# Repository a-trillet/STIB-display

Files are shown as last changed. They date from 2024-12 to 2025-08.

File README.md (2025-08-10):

# Brussels transport lines Display
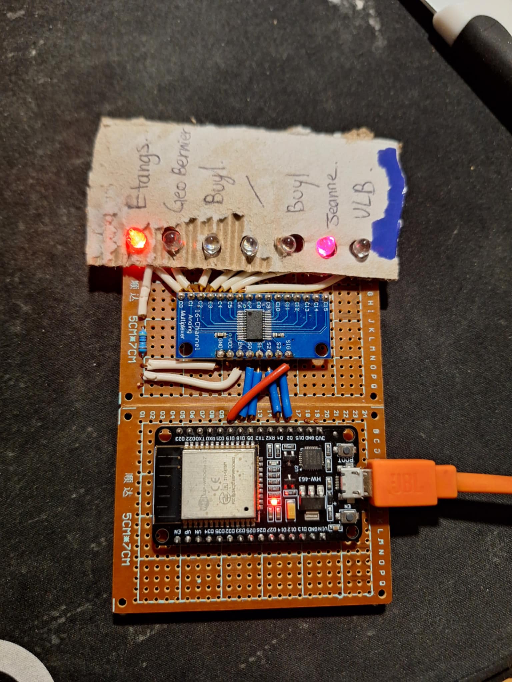
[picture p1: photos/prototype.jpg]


## What you need
- ESP32 devkit (we used esp32 WROOM devkit1)
- 16 channel MUX (for maximum 16 LEDs)
- basic electronic componenents (leds, resistor, test board or PCB...)  

(Not yet ready !)
For a complete list of electronic components and the references we used, refer to [hardware section](./hardware/).   
In the same section, the PCB kicad files can be downloaded and you can order them through any PCB manufacturer. 

## Getting started with the STIB API
- Create an account on https://data.stib-mivb.brussels/pages/home/
- Generate API key on https://data.stib-mivb.brussels/account/api-keys/
- Test the api with [request.py](./pc-test/request.py)
    - Change the ****  in the request header with the generated API key
    - Running `python request.py` will show buses location on line 71, you will want to adapt stop IDs to the line you are interested in. You can get all stop IDs for all lines using the WEB API for stops information:  [stops-by-line-production](https://data.stib-mivb.brussels/explore/dataset/stops-by-line-production/api/)

## Getting started on ESP 32
The following steps and requirements are provided for Windows.
- Download the latest micropython firmware for esp32 here : [micropython firmware](https://micropython.org/download/ESP32_GENERIC/)
- Download useful python tools: 
    - `pip install esptool`
    - `pip install adafruit-ampy`
- Erase flash of ESP: `python -m esptool --chip esp32 erase_flash`
- Flash ESP with micropython firmware: `python -m esptool --chip esp32 --port COMX write_flash -z 0x1000 ESP32_GENERIC-20241129-v1.24.1.bin`
- Adpat **** in main.py with your API key and Wifi credentials
- Send main.py to the ESP to be executed automatically: `<path\to\ampy.exe> --port COMX put <path\to\main.py>`
- Get buses position through serial communication (using Putty per example)
```
LED 3 activée
Bus à: 3559 - ULB vers Jeanne 3559
LED 5 activée
Bus à: 2397 - Buyl(delta) vers ULB 2397
LED 3 activée
Bus à: 3525 - Jeanne vers Buyl 3525
LED 4 activée
```

Like us, you might need to: 
- Download the CP210x driver for ESP USB to UART bridge: [download CP210x](https://www.silabs.com/developer-tools/usb-to-uart-bridge-vcp-drivers?tab=downloads)
- Change the baudrate for the discovered device in device manager to **115200**
- Don't forget to close putty before writing to it

Get more detailed steps: https://docs.micropython.org/en/latest/esp32/tutorial/intro.html  

## Make it ! 
Instructions, schematics and PCBs layout can be found under [hardware section](./hardware/). 

And in the code you will have to adapt the list of stops you want to see with the stop IDs available on STIB web API. Also you will have to change the channel number of each led that has to turn on in the dictionnary with bus stops. (currently only one MUX). 

## CC License 
All work in this project is openly licensed via [CC BY-NC 4.0](https://creativecommons.org/licenses/by-nc/4.0/).

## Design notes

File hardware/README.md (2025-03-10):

# PCB layout
Helpful ressources for kicad V8,: [Kicad 8 - Getting Started](https://docs.kicad.org/8.0/en/getting_started_in_kicad/getting_started_in_kicad.html)

PCB can easily be manufactured at any PCB manufacturer. I ordered mine at JCLPCB by uploading the gerber and drill files for each board.   
I had to regenerate those with one board only at a time (deleting the rest on the pcb layout). 
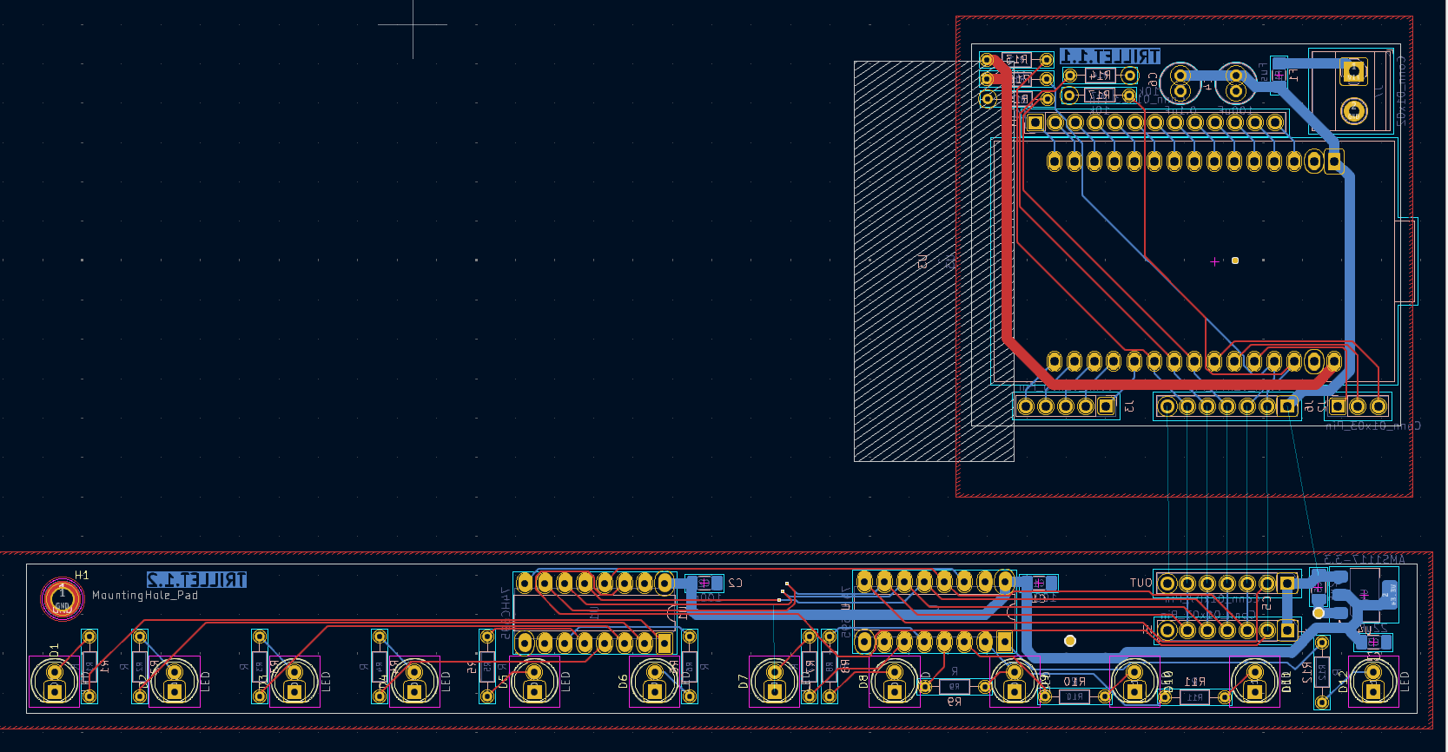
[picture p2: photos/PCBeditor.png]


The idea is to solder the LED boards in serie, one per line wanted in the final design: 
- J6 Pins of the ESP32 board (Trillet 1.1) go to IN pin of first LED board (Trillet 1.2)
- Pins OUT of the first LED board go to IN pin of the next LED board
## BOM 
### LED board
|Amount|Component|Ref number|
|-|-|-|
| 1 | 3.3v linear voltage regulator | [AMS1117-3.3V](https://www.alldatasheet.com/datasheet-pdf/pdf/205691/ADMOS/AMS1117-3.3.html) |
| 2 | 100nF SMD Capacitor | 100nF 1206 SMD:C |
| 2 | 22uF SMD Capacitor | 22uF 1206 SMD:C |
| 2 | 8bit shift register | [SN74HC595N (THT) ](https://www.alldatasheet.fr/datasheet-pdf/download/27939/TI/SN74HC595N.html) |
| 12 | LED THT | 5mm THT LED|
| 12 | Resistor THT (see value below)| DIN 0204 R THT 3.6 mm |
| 1 | 7  pin JST connector (female + male + cable) | [2.54 mm JST male/ + female](https://fr.aliexpress.com/item/32964549472.html)  |

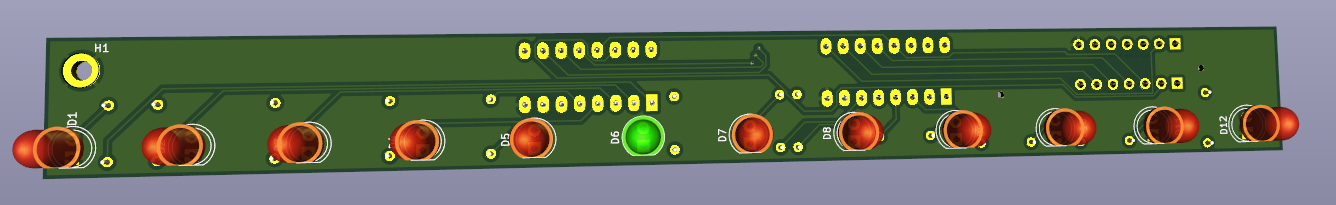
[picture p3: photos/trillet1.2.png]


### ESP 32 - Power board
|Amount|Component|Ref number|
|-|-|-|
| 1 | Terminal copnnector block 5mm - 2Pin | [ZR301-2P-Green-50](https://fr.aliexpress.com/item/1005007055503766.html) |
| 5 | 10 k Ohm  Resistor | 10k Ohm - DIN 0204 R THT 3.6 mm|
| 1 | 3.5 A SMD fuse | [3.5A 1206 SMD:Fuse](https://fr.aliexpress.com/item/32901034711.html) |
| 2 | ESP 32 Wroom-32 Nodemcu type C | [esp32 devkit  (check pinout!)](https://fr.aliexpress.com/item/1005006478818552.html) |
| 1 | 100nF THT polarized electrolitic capacitor | 5mm THT:C |
| 1 | 100uF THT polarized electrolitic capacitor | 5mm THT:C |
| 1 | 7  pin JST connector (female + male + cable) | [2.54 mm JST male/ + female](https://fr.aliexpress.com/item/32964549472.html)  |

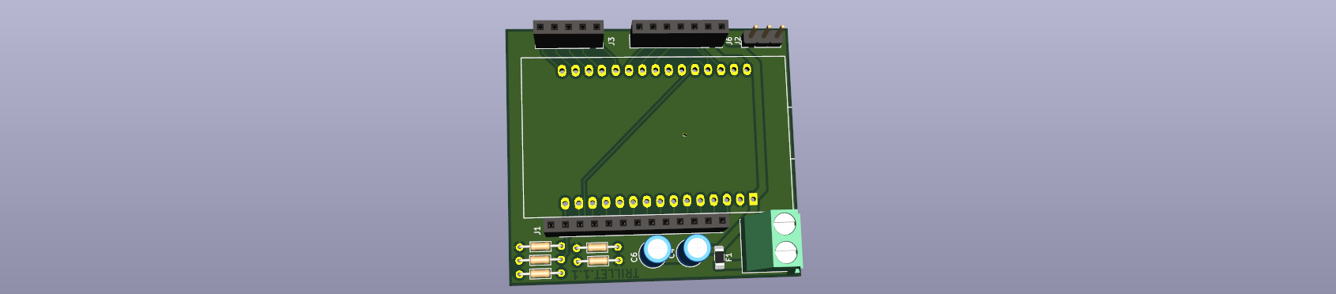
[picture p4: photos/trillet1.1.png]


## LED to Resitor value

TODO

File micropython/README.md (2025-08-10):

# Erase flash first
python -m esptool --chip esp32 --port COM3 erase_flash

# Flash the OTA upython firmware
python -m esptool --chip esp32 --port COM3 --baud 460800 write_flash -z 0x1000 .\arduino-esp32\ESP32_GENERIC-OTA-20250415-v1.25.0.bin

# Flash the compile python code
mpremote connect COM3 cp -r bus_display_led\ :
mpremote connect COM3 cp main.py :

ref: 5c:01:3b:67:9c:ec
import bus_display_led.main as app_main

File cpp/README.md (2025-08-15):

https://docs.espressif.com/projects/esp-idf/en/stable/esp32/get-started/linux-macos-setup.html

# wsl2 tool for flashing 

curl https://git.io/JyBgj --create-dirs -L -o $HOME/bin/idfx && chmod u+x $HOME/bin/idfx
https://developer.espressif.com/blog/espressif-devkits-with-wsl2/

https://github.com/abobija/idfx

# if windows is prefered: 
https://dl.espressif.com/dl/esp-idf/

# TLS
disabled verification -> to reanable with PEM in production

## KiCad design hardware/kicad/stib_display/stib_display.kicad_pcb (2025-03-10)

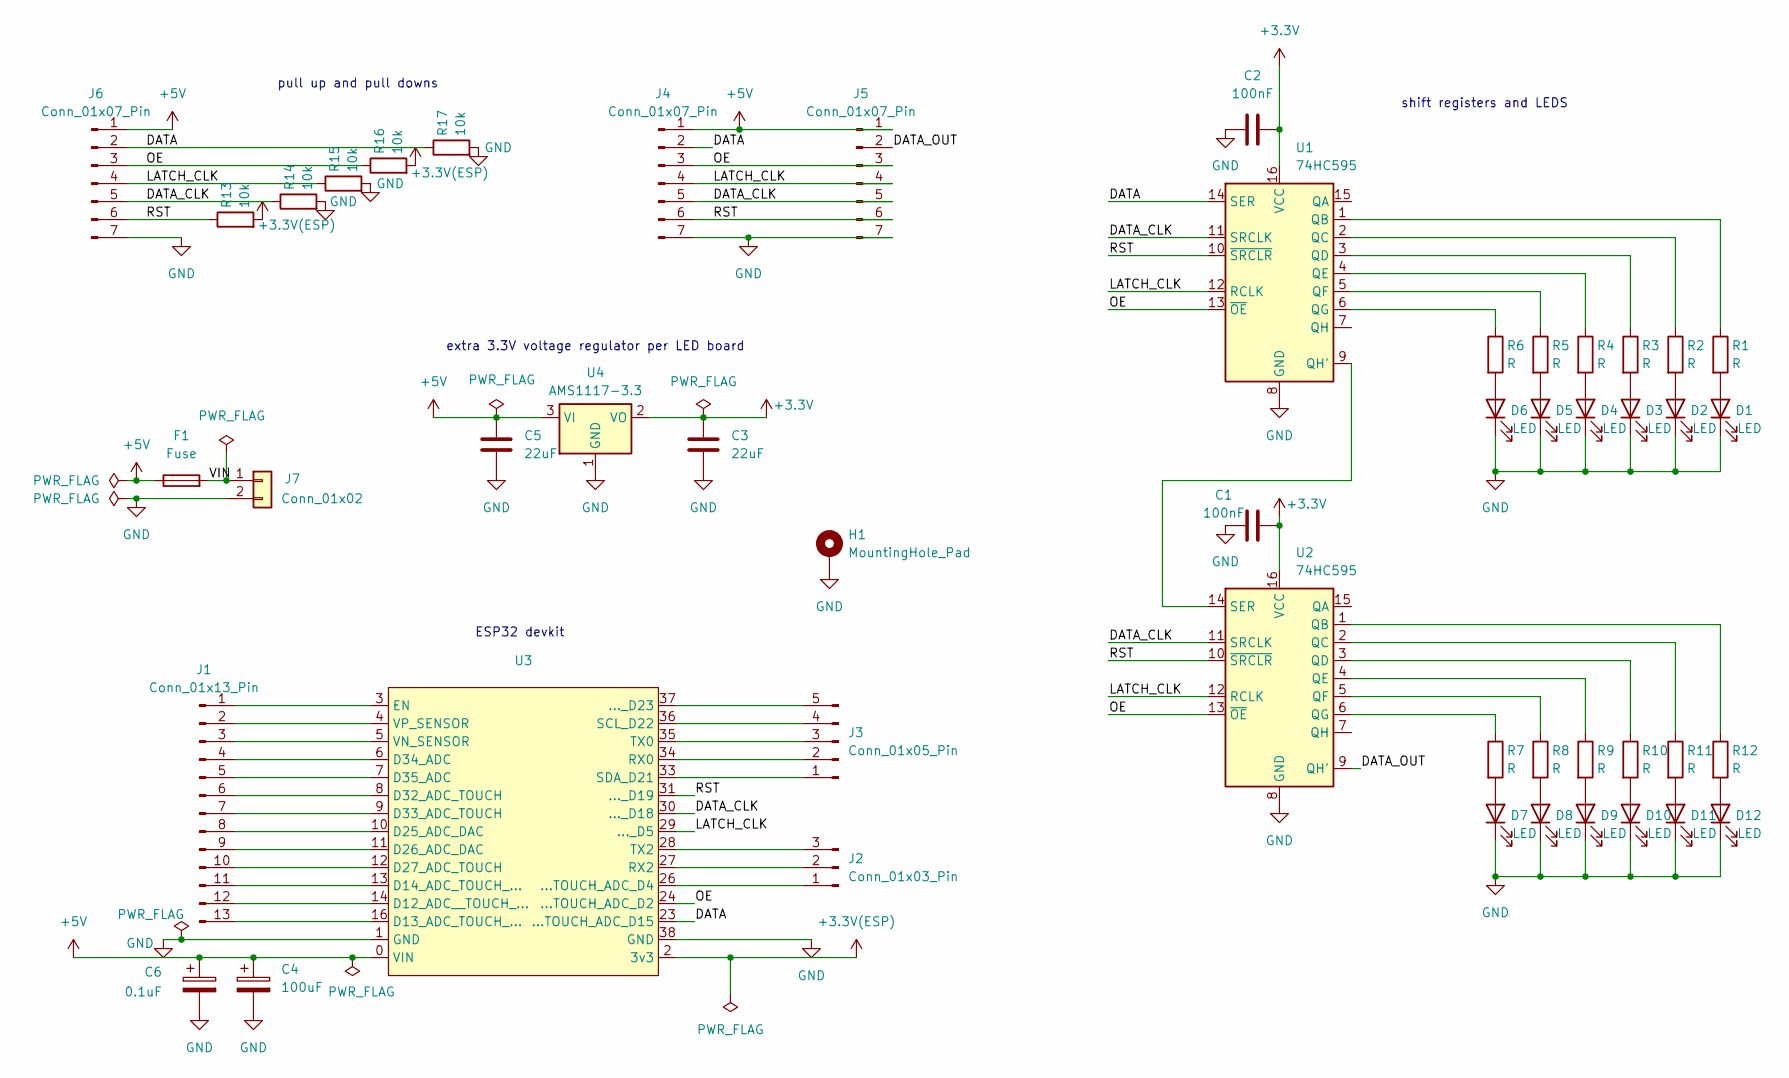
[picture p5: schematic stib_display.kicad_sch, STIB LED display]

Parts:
C1, C2: 100nF; C_1206_3216Metric_Pad1.33x1.80mm_HandSolder
C3, C5: 22uF; C_1206_3216Metric_Pad1.33x1.80mm_HandSolder
C4: 100uF; C_Radial_D5.0mm_H11.0mm_P2.00mm
C6: 0.1uF; C_Radial_D5.0mm_H11.0mm_P2.00mm
D1, D2, D3, D4, D5, D6, D7, D8, D9, D10, D11, D12: LED; LED_D5.0mm
F1: Fuse; Fuse_1206_3216Metric_Pad1.42x1.75mm_HandSolder
H1: MountingHole_Pad; MountingHole_2.7mm_M2.5_DIN965_Pad_TopBottom
J1: Conn_01x13_Pin; PinSocket_1x13_P2.54mm_Vertical
J2: Conn_01x03_Pin; PinHeader_1x03_P2.54mm_Vertical
J3: Conn_01x05_Pin; PinSocket_1x05_P2.54mm_Vertical
J4, J5, J6: Conn_01x07_Pin; PinSocket_1x07_P2.54mm_Vertical
J7: Conn_01x02; TerminalBlock_Phoenix_MKDS-1,5-2_1x02_P5.00mm_Horizontal
R1, R2, R3, R4, R5, R6, R7, R8, R9, R10, R11, R12: R; R_Axial_DIN0204_L3.6mm_D1.6mm_P7.62mm_Horizontal
R13, R14, R15, R16, R17: 10k; R_Axial_DIN0204_L3.6mm_D1.6mm_P7.62mm_Horizontal
U1, U2: 74HC595; DIP-16_W7.62mm_LongPads
U3: ESP32_Nodemcu_devkit
U4: AMS1117-3.3; SOT-223-3_TabPin2

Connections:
+3.3V: C1.2, C2.2, C3.1, U1.16 (VCC), U2.16 (VCC), U4.2 (VO)
+3.3V(ESP): R13.2, R16.2, U3.2 (3v3)
+5V: C4.1, C5.1, C6.1, F1.1, J4.1, J5.1, J6.1, U3.0 (VIN), U4.3 (VI)
/DATA: J4.2, J6.2, R17.1, U1.14 (SER), U3.23 (...TOUCH_ADC_D15)
/DATA_CLK: J4.5, J5.5, J6.5, R14.1, U1.11 (SRCLK), U2.11 (SRCLK), U3.30 (..._D18)
/DATA_OUT: J5.2, U2.9 (QH')
/LATCH_CLK: J4.4, J5.4, J6.4, R15.1, U1.12 (RCLK), U2.12 (RCLK), U3.29 (..._D5)
/OE: J4.3, J5.3, J6.3, R16.1, U1.13 (~OE), U2.13 (~OE), U3.24 (...TOUCH_ADC_D2)
/RST: J4.6, J5.6, J6.6, R13.1, U1.10 (~SRCLR), U2.10 (~SRCLR), U3.31 (..._D19)
/VIN: F1.2, J7.1
GND: C1.1, C2.1, C3.2, C4.2, C5.2, C6.2, D1.1 (K), D2.1 (K), D3.1 (K), D4.1 (K), D5.1 (K), D6.1 (K), D7.1 (K), D8.1 (K), D9.1 (K), D10.1 (K), D11.1 (K), D12.1 (K), H1.1, J4.7, J5.7, J6.7, J7.2, R14.2, R15.2, R17.2, U1.8 (GND), U2.8 (GND), U3.1 (GND), U3.38 (GND), U4.1 (GND)
unnamed: D1.2 (A), R1.2
unnamed: D2.2 (A), R2.2
unnamed: D3.2 (A), R3.2
unnamed: D4.2 (A), R4.2
unnamed: D5.2 (A), R5.2
unnamed: D6.2 (A), R6.2
unnamed: D7.2 (A), R7.2
unnamed: D8.2 (A), R8.2
unnamed: D9.2 (A), R9.2
unnamed: D10.2 (A), R10.2
unnamed: D11.2 (A), R11.2
unnamed: D12.2 (A), R12.2
unnamed: J1.1, U3.3 (EN)
unnamed: J1.2, U3.4 (VP_SENSOR)
unnamed: J1.3, U3.5 (VN_SENSOR)
unnamed: J1.4, U3.6 (D34_ADC)
unnamed: J1.5, U3.7 (D35_ADC)
unnamed: J1.6, U3.8 (D32_ADC_TOUCH)
unnamed: J1.7, U3.9 (D33_ADC_TOUCH)
unnamed: J1.8, U3.10 (D25_ADC_DAC)
unnamed: J1.9, U3.11 (D26_ADC_DAC)
unnamed: J1.10, U3.12 (D27_ADC_TOUCH)
unnamed: J1.11, U3.13 (D14_ADC_TOUCH_...)
unnamed: J1.12, U3.14 (D12_ADC__TOUCH_...)
unnamed: J1.13, U3.16 (D13_ADC_TOUCH_...)
unnamed: J2.1, U3.26 (...TOUCH_ADC_D4)
unnamed: J2.2, U3.27 (RX2)
unnamed: J2.3, U3.28 (TX2)
unnamed: J3.1, U3.33 (SDA_D21)
unnamed: J3.2, U3.34 (RX0)
unnamed: J3.3, U3.35 (TX0)
unnamed: J3.4, U3.36 (SCL_D22)
unnamed: J3.5, U3.37 (..._D23)
unnamed: R1.1, U1.1 (QB)
unnamed: R2.1, U1.2 (QC)
unnamed: R3.1, U1.3 (QD)
unnamed: R4.1, U1.4 (QE)
unnamed: R5.1, U1.5 (QF)
unnamed: R6.1, U1.6 (QG)
unnamed: U1.9 (QH'), U2.14 (SER)
unnamed: R12.1, U2.1 (QB)
unnamed: R11.1, U2.2 (QC)
unnamed: R10.1, U2.3 (QD)
unnamed: R9.1, U2.4 (QE)
unnamed: R8.1, U2.5 (QF)
unnamed: R7.1, U2.6 (QG)

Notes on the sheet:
pull up and pull downs
shift registers and LEDS
extra 3.3V voltage regulator per LED board
ESP32 devkit

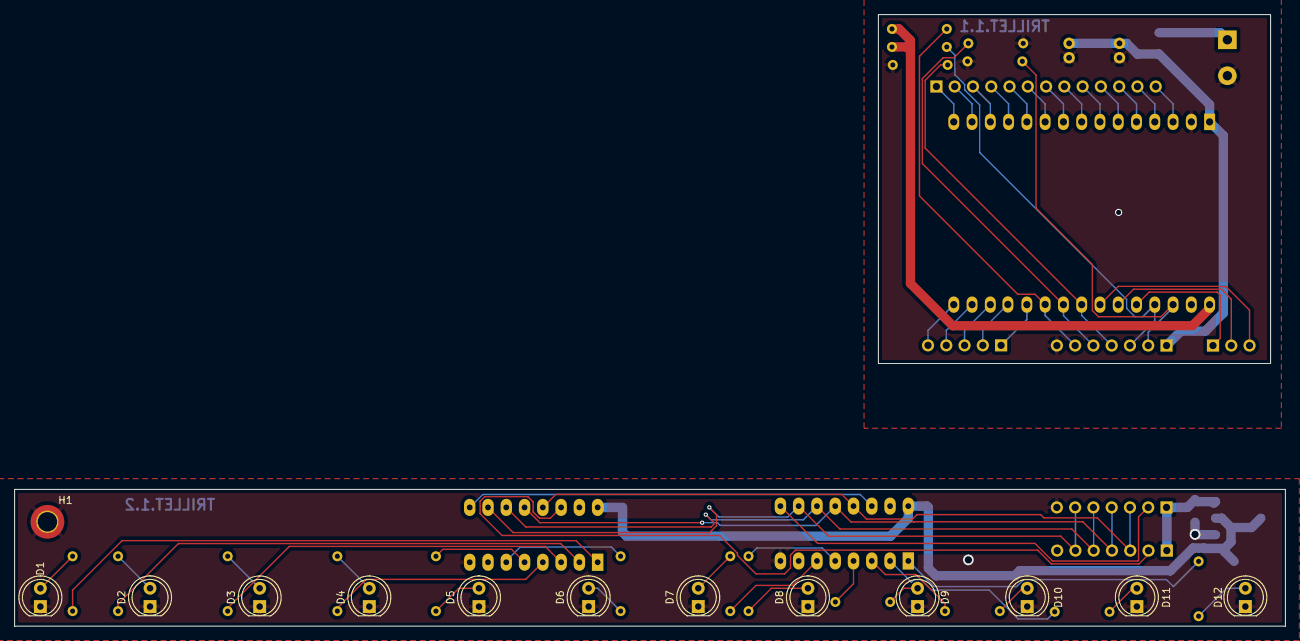
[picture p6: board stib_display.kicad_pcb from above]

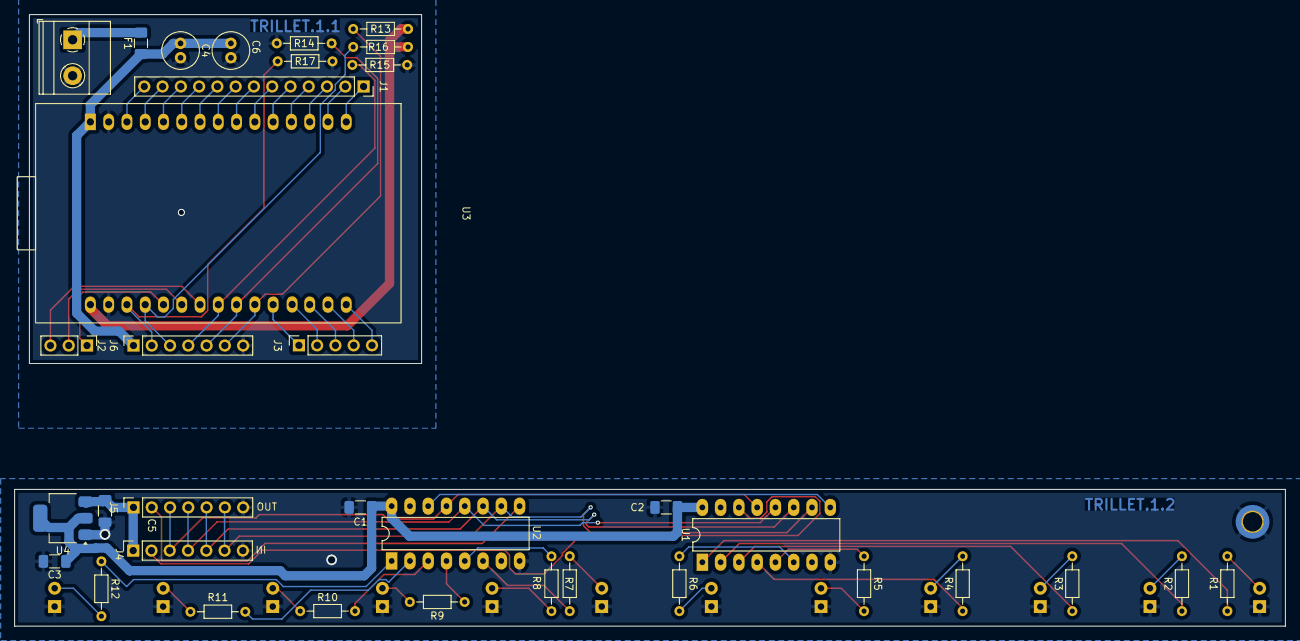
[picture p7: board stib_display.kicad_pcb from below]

Board: 2 copper layers, 176.6 x 85.0 mm, 48 parts (35 on the bottom side), 57 nets.

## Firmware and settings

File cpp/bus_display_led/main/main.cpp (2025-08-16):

// main.cpp
#include <stdio.h>
#include "esp_log.h"
#include "freertos/FreeRTOS.h"
#include "freertos/task.h"
#include "nvs_flash.h"
#include "led_controller.h"
#include "wifi_manager.h"
#include "web_server.h"
#include "led_updater.h"
#include "storage_manager.h"
#include "ota_manager.h"

static const char* TAG = "MAIN";

// Global objects
LEDController* led_controller = nullptr;
StorageManager* storage_manager = nullptr;
WiFiManager* wifi_manager = nullptr;
WebServer* web_server = nullptr;
LEDUpdater* led_updater = nullptr;
OTAManager* ota_manager = nullptr;

// WiFi configuration callback from web server
void wifi_config_callback(const std::string& ssid, const std::string& password) {
    ESP_LOGI(TAG, "New WiFi credentials received: %s", ssid.c_str());
    
    // Connect with save=true to store credentials
    wifi_manager->connect_sta(ssid, password, true);
}

// Task for initial OTA check (runs once)
void initial_ota_check_task(void* param) {
    ESP_LOGI(TAG, "Initial OTA check task started");
    
    // Wait for WiFi connection
    int max_wait = 30; // 30 seconds
    while (!wifi_manager->is_connected() && max_wait > 0) {
        vTaskDelay(pdMS_TO_TICKS(1000));
        max_wait--;
    }
    
    if (wifi_manager->is_connected()) {
        ESP_LOGI(TAG, "Performing initial OTA check...");
        ota_manager->check_for_updates();
    } else {
        ESP_LOGI(TAG, "No WiFi connection, skipping initial OTA check");
    }
    
    ESP_LOGI(TAG, "Initial OTA check task completed");
    vTaskDelete(NULL);
}

extern "C" void app_main(void)
{
    ESP_LOGI(TAG, "Bus Display LED - ESP-IDF Version Starting");
    ESP_LOGI(TAG, "ESP-IDF Version: %s", esp_get_idf_version());
    
    // Initialize NVS (required for WiFi and storage)
    esp_err_t ret = nvs_flash_init();
    if (ret == ESP_ERR_NVS_NO_FREE_PAGES || ret == ESP_ERR_NVS_NEW_VERSION_FOUND) {
        ESP_ERROR_CHECK(nvs_flash_erase());
        ret = nvs_flash_init();
    }
    ESP_ERROR_CHECK(ret);

    // Create storage manager
    storage_manager = new StorageManager();
    if (!storage_manager->initialize()) {
        ESP_LOGE(TAG, "Failed to initialize storage manager");
        return;
    }
    ESP_LOGI(TAG, "Storage manager initialized successfully");
    
    // Create LED controller
    led_controller = new LEDController();
    if (!led_controller->initialize()) {
        ESP_LOGE(TAG, "Failed to initialize LED controller");
        return;
    }
    ESP_LOGI(TAG, "LED controller initialized successfully");
    
    led_controller->set_all(false); // Ensure LEDs start off
    led_controller->set_all(true); // check if LEDs are working
    vTaskDelay(pdMS_TO_TICKS(1000));    
    //led_controller->set_all(false); // turn off LEDs after check
    //led_controller->test_sequence(); // check if LEDs are working
    
    // Create WiFi manager
    wifi_manager = new WiFiManager(*storage_manager);
    if (!wifi_manager->initialize()) {
        ESP_LOGE(TAG, "Failed to initialize WiFi manager");
        return;
    }
    ESP_LOGI(TAG, "WiFi manager initialized successfully");

    // Initialize OTA manager
    ota_manager = new OTAManager(*wifi_manager, *led_controller);
    if (!ota_manager->initialize()) {
        ESP_LOGE(TAG, "Failed to initialize OTA manager");
        return;
    }
    ESP_LOGI(TAG, "OTA manager initialized successfully");

    // Check if we have saved WiFi credentials and try to connect
    if (storage_manager->has_wifi_credentials()) {
        ESP_LOGI(TAG, "Found saved WiFi credentials, attempting connection...");
        std::string ssid, password;
        if (storage_manager->load_wifi_credentials(ssid, password)) {
            wifi_manager->connect_sta(ssid, password, false); // Don't save again
        }
    } else {
        ESP_LOGI(TAG, "No saved WiFi credentials found");
    }
    
    // Start auto-connect task for handling reconnections
    wifi_manager->start_auto_connect_task();
    
    // Start AP mode
    if (!wifi_manager->start_ap_mode()) {
        ESP_LOGE(TAG, "Failed to start AP mode");
        return;
    }
    ESP_LOGI(TAG, "AP mode started: %s", WIFI_AP_SSID);
    
    // Create and start web server
    web_server = new WebServer(*wifi_manager);
    web_server->set_wifi_config_callback(wifi_config_callback);
    web_server->set_ota_manager(*ota_manager);
    
    if (!web_server->start()) {
        ESP_LOGE(TAG, "Failed to start web server");
        return;
    }
    ESP_LOGI(TAG, "Web server started successfully");
    ESP_LOGI(TAG, "Connect to WiFi '%s' and go to http://192.168.4.1", WIFI_AP_SSID);
    
    // Create LED updater
    led_updater = new LEDUpdater(*led_controller, *wifi_manager);

    // Start LED update task
    xTaskCreate([](void* param) {
        LEDUpdater* updater = static_cast<LEDUpdater*>(param);
        while (true) {
            if (wifi_manager->is_connected()) {
                updater->fetch_and_update();
            }
            vTaskDelay(pdMS_TO_TICKS(5000));
        }
    }, "led_update_task", 4096, led_updater, 5, NULL);

    // Start OTA update timer (checks every hour)
    ota_manager->start_ota_timer();
    
    ESP_LOGI(TAG, "System initialization complete!");
    ESP_LOGI(TAG, "Device MAC: %s", wifi_manager->get_mac_address().c_str());
    ESP_LOGI(TAG, "Current firmware version: %s", ota_manager->get_current_version().c_str());
    
    // Create separate task for initial OTA check with larger stack
    xTaskCreate(initial_ota_check_task, "initial_ota_check", 8192, NULL, 5, NULL);
    
    // Main loop - monitor system status
    while (1) {
        ESP_LOGI(TAG, "Status - AP: %s, STA: %s, Web: %s, OTA: %s", 
                 wifi_manager->is_ap_active() ? "ON" : "OFF",
                 wifi_manager->is_connected() ? "CONNECTED" : "DISCONNECTED",
                 web_server->is_running() ? "RUNNING" : "STOPPED",
                 ota_manager->get_last_check_status().c_str());
        
        if (wifi_manager->is_connected()) {
            ESP_LOGI(TAG, "WiFi Status: %s, IP: %s", 
                     wifi_manager->get_connection_status().c_str(),
                     wifi_manager->get_ip_address().c_str());
        }
        
        vTaskDelay(pdMS_TO_TICKS(30000)); // Status update every 30 seconds
    }
}

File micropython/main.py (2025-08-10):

import machine
import sys
import gc
import time
import os

SLOT_A = "slot_a"
SLOT_B = "slot_b"
ACTIVE_FILE = "active_slot.txt"

def logerror(e=None):
    with open('error.log', 'w') as f:
        if e:
            f.write(str(e) + '\n')
        else:
            f.write('Unknown error\n')
    with open('error_sent', 'w') as f:
        f.write('1')

def get_active_slot():
    if ACTIVE_FILE in os.listdir():
        with open(ACTIVE_FILE, 'r') as f:
            slot = f.read().strip()
            if slot in (SLOT_A, SLOT_B):
                return slot
    return SLOT_A  # default if file missing

def set_active_slot(slot):
    with open(ACTIVE_FILE, 'w') as f:
        f.write(slot)

def other_slot(slot):
    return SLOT_B if slot == SLOT_A else SLOT_A

def try_run(slot):
    print(f"=== Booting from {slot} ===")
    sys.path.insert(0, slot)
    try:
        from bus_display_led import main as app_main
        result = app_main.main()
        print(f"{slot} exited with return value:", result)
        logerror(f"{slot} returned: {result}")
        return False
    except Exception as e:
        print(f"Error in {slot}:", e)
        logerror(e)
        return False
    finally:
        sys.path.pop(0)

def safe_boot():
    active = get_active_slot()
    inactive = other_slot(active)

    if try_run(active):
        print(f"{active} ran successfully.")
        return

    print(f"{active} failed — trying {inactive}...")
    if try_run(inactive):
        print(f"{inactive} ran successfully — setting it as active.")
        set_active_slot(inactive)
        return

    print("Both slots failed! Waiting for manual intervention.")

if __name__ == "__main__":
    safe_boot()
    sleep_time = 10
    print(f"Sleeping for {sleep_time} seconds before rebooting...")
    time.sleep(sleep_time)
    print("Rebooting...")
    gc.collect()
    machine.reset()

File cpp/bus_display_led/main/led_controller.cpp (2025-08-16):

// led_controller.cpp
#include "led_controller.h"
#include "rom/ets_sys.h"

const char* LEDController::TAG = "LED_CTRL";

// LED to register bit mapping (matching your MicroPython code)
const uint16_t LEDController::led_to_register[12] = {
    0b0100000000000000,      // LED 1
    0b0010000000000000,      // LED 2
    0b0001000000000000,      // LED 3
    0b0000100000000000,      // LED 4
    0b0000010000000000,      // LED 5
    0b0000001000000000,      // LED 6
    0b0000000000000010,      // LED 7
    0b0000000000000100,      // LED 8
    0b0000000000001000,      // LED 9
    0b0000000000010000,      // LED 10
    0b0000000000100000,      // LED 11
    0b0000000001000000,      // LED 12
};

LEDController::LEDController() : initialized_(false) {
}

LEDController::~LEDController() {
    if (initialized_) {
        clear_all();
        gpio_reset_pin(CLOCK_PIN);
        gpio_reset_pin(DATA_PIN);
        gpio_reset_pin(LATCH_PIN);
        gpio_reset_pin(RESET_PIN);
        gpio_reset_pin(OE_PIN);
    }
}

bool LEDController::initialize() {
    ESP_LOGI(TAG, "Initializing LED controller pins");
    
    // Configure all pins as outputs
    gpio_config_t io_conf = {};
    io_conf.intr_type = GPIO_INTR_DISABLE;
    io_conf.mode = GPIO_MODE_OUTPUT;
    io_conf.pin_bit_mask = (1ULL << CLOCK_PIN) | (1ULL << DATA_PIN) | 
                           (1ULL << LATCH_PIN) | (1ULL << RESET_PIN) | (1ULL << OE_PIN);
    io_conf.pull_down_en = GPIO_PULLDOWN_DISABLE;
    io_conf.pull_up_en = GPIO_PULLUP_DISABLE;
    
    esp_err_t ret = gpio_config(&io_conf);
    if (ret != ESP_OK) {
        ESP_LOGE(TAG, "GPIO config failed: %s", esp_err_to_name(ret));
        return false;
    }
    
    // Initialize pins to safe state (matching your MicroPython init_pins())
    gpio_set_level(OE_PIN, 1);        // Disable output (high impedance)
    gpio_set_level(LATCH_PIN, 0);
    gpio_set_level(CLOCK_PIN, 0);
    gpio_set_level(DATA_PIN, 0);
    
    // Reset shift register
    pulse_pin(RESET_PIN);             // Put low to reset shift register
    gpio_set_level(RESET_PIN, 1);     // Keep high to prevent resetting
    
    // Put 0s in latches
    pulse_pin(LATCH_PIN);
    
    // Enable output
    gpio_set_level(OE_PIN, 0);
    
    initialized_ = true;
    ESP_LOGI(TAG, "LED controller initialized successfully");
    return true;
}

void LEDController::pulse_pin(gpio_num_t pin) {
    ets_delay_us(PULSE_DELAY_US);
    gpio_set_level(pin, 1);
    ets_delay_us(PULSE_DELAY_US * 2);
    gpio_set_level(pin, 0);
    ets_delay_us(PULSE_DELAY_US);
}

void LEDController::feed_register(uint16_t value) {
    // Send each bit (from LSB to MSB) - matching your MicroPython code
    for (int i = 0; i < 16; i++) {
        int bit = (value >> i) & 1;  // Extract the bit (starting from LSB)
        gpio_set_level(DATA_PIN, bit);
        pulse_pin(CLOCK_PIN);
    }
    gpio_set_level(DATA_PIN, 0);     // Reset to 0 in idle state
}

void LEDController::latch_data() {
    pulse_pin(LATCH_PIN);
}

void LEDController::set_leds(uint16_t pattern) {
    if (!initialized_) {
        ESP_LOGE(TAG, "LED controller not initialized");
        return;
    }
    
    feed_register(pattern);
    latch_data();
    ESP_LOGD(TAG, "Set LEDs with pattern: 0x%04X", pattern);
}

void LEDController::set_single_led(int led_number) {
    if (!initialized_) {
        ESP_LOGE(TAG, "LED controller not initialized");
        return;
    }
    
    if (led_number < 1 || led_number > 12) {
        ESP_LOGW(TAG, "Invalid LED number: %d (valid range: 1-12)", led_number);
        return;
    }
    
    uint16_t pattern = led_to_register[led_number];
    set_leds(pattern);
    ESP_LOGI(TAG, "Set LED %d (pattern: 0x%04X)", led_number, pattern);
}

void LEDController::clear_all() {
    if (!initialized_) {
        ESP_LOGE(TAG, "LED controller not initialized");
        return;
    }
    
    set_leds(0x0000);
    ESP_LOGI(TAG, "All LEDs cleared");
}

void LEDController::set_all(const bool state) {
    const size_t row_count = 10;
    bool rows[row_count][12] = {0};

    for (size_t r = 0; r < row_count; r++) {
        for (int i = 0; i < 12; i++) {
            rows[r][i] = state;
        }
    }

    set_rows(rows, row_count);
}

void LEDController::set_rows(const bool rows[][12], size_t row_count) {
    if (!initialized_) {
        ESP_LOGE(TAG, "LED controller not initialized");
        return;
    }

    for (size_t r = 0; r < row_count; r++) {
        uint16_t pattern = 0;
        for (size_t i = 0; i < 12; i++) {
            if (rows[r][i]) {
                pattern |= led_to_register[i];
            }
        }
        feed_register(pattern);  // feed each row sequentially
    }

    latch_data();  // latch after all rows are fed
}

// Updated test_sequence to use 4 rows
void LEDController::test_sequence() {
    const size_t row_count = 4;
    bool rows[row_count][12] = {0};

    for (int led = 0; led < 12; led++) {
        // Clear all LEDs
        for (size_t r = 0; r < row_count; r++) {
            memset(rows[r], 0, sizeof(rows[r]));
            rows[r][led] = true;  // turn on the current LED in each row
        }

        ESP_LOGI(TAG, "Testing LED %d in %d rows", led, row_count);
        set_rows(rows, row_count);

        // wait 1 second before next LED
        ets_delay_us(1000000);  // 1 second
    }
}

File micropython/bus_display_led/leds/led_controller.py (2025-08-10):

# led_controller.py
import time
from machine import Pin
import urequests as requests
from bus_display_led.config import server_url, ledstrip_endpoint
from bus_display_led.wifi.wifi_sta import wifi_status


# Pin definitions
CLOCK_PIN = 18   # GPIO 18 for clock
DATA_PIN = 15    # GPIO 15 for data
LATCH_PIN = 5    # GPIO 2 for the latch pin (RCLK)
RESET_PIN = 19    # GPIO 19 for the register reset pin
OE_PIN = 2    # GPIO 35 for the register reset pin

# Mapping LEDs to register values
led_to_register = {
    1: 0b0100000000000000,
    2: 0b0010000000000000,
    3: 0b0001000000000000,
    4: 0b0000100000000000,
    5: 0b0000010000000000,
    6: 0b0000001000000000,
    7: 0b0000000000000010,
    8: 0b0000000000000100,
    9: 0b0000000000001000,
    10: 0b0000000000010000,
    11: 0b0000000000100000,
    12: 0b0000000001000000,
}

# Pin initialization
clock   = Pin(CLOCK_PIN, Pin.OUT)
data    = Pin(DATA_PIN, Pin.OUT)
latch   = Pin(LATCH_PIN, Pin.OUT)
reset   = Pin(RESET_PIN, Pin.OUT)
oe      = Pin(OE_PIN, Pin.OUT)

def pulse(pin):
    """
    Generates a clock pulse on the given pin. (+- 10kHz, max 15MHz)
    """
    time.sleep_us(25)
    pin.on()
    time.sleep_us(50)
    pin.off()
    time.sleep_us(25)


def feed_register(leds):
    """
    Sends a 16-bit value to the shift register, LSB first.

    :param row: The row number (1-4).
    :param leds: A 16-bit integer representing the LED states.
    """
    # Send each bit (from LSB to MSB)
    for i in range(16):
        bit = (leds >> i) & 1  # Extract the bit (starting from LSB)
        data.value(bit)       # Set the data line
        pulse(clock)     # Pulse the clock pin
    data.value(0)             # reset to 0 in idle state


def init_pins():
    print("Initialising pins")
    oe.on() #disable output (high impedance)
    latch.off()
    clock.off()
    data.off() 
    pulse(reset) # put low to reset shift register 
    reset.on() # keep on to prevent reseting the registers
    pulse(latch) # put 0s in latches
    oe.off() # keep down to enable output 

def update_leds(value):
    """ Update the LEDs by sending a value to the shift register."""
    feed_register(led_to_register[value])
    pulse(latch)  # Latch the data into the output register


# Fetch data and update LEDs
def fetch_update_leds():
    """
    Fetch LED strip status and update shift registers.
    """
    try:
        global last_response
        url = f"{server_url}{ledstrip_endpoint}{wifi_status['mac']}"
        last_response = requests.get(url, timeout=5)
        if last_response.status_code != 200:
            print("Error:", last_response.json())
            return last_response.status_code

        data = last_response.json()
        strips = data.get('strips', [])
        for strip in strips:
            leds = strip.get('v', [])
            register_value = 0
            for i, val in enumerate(leds):
                if val and (i + 1) in led_to_register:
                    register_value |= led_to_register[i + 1]
            feed_register(register_value)
        pulse(latch)
        return last_response.status_code
    
    except Exception as e:
        print("Exception:", e)
        return -1

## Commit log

2025-03-10 new board based on shift registers + kicad files + BOMs
    [boards.kicad_pcb, boards.kicad_sch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]
2025-08-15 new partiotioning for ota
    [partitions.csv]
2025-08-16 working led updater, first attempt for updater
